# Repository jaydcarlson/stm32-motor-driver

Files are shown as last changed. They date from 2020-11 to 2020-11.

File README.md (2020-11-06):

# stm32-motor-driver
Altium PCB files and STM32CubeIDE project to implement a basic brushed DC motor controller.

## Demo Usage
The STM32 will respond to commands sent on the UART pins at a baud of 115,200. You can use [PuTTY](https://www.putty.org/) or some other serial terminal to communicate with the board using a USB-to-serial converter.

The board will announce itself on boot-up; if you don't see `STM32 Motor Driver, v1.0` printed on your console, check your TX/RX polarity, your baud, and that you are connected to the correct COM port.

The only command the interface currently supports is the "goto" command. Invoke it as `g [setpoint]`. The board will respond by announcing the setpoint and announcing when it is reached.

Examples:
```
g 1000
GO 1000...Reached

g -500
GO -500...Reached
```

## Building the Firmware
You should fork the repo on GitHub to provide you with a version-controlled environment to develop and backup your code. GitHub offers the [GitHub Desktop](https://desktop.github.com/) client, but there are many ways — including the command-line `git` tool — to manage local and remote git repositories.

You'll need STM32CubeIDE installed to build the firmware. Invoke the **File > Import**  command to open the Import dialog. 

Choose **General > Existing Projects into Workspace** and hit **Next**.

Choose the **Select root directory** radio button and hit **Browse** to select the firmware folder. STM32CubeIDE should automatically discover the project and allow you to import it by selecting it with a checkbox and clicking **Finish**.

## Pin Mapping
* PA10 and PA8 are wired as separate PWM channels (TIM1_CH3 and TIM1_CH1) for the INA and INB signals, respectively.
* PA9 is routed to the "PWM" pin — if you want to recirculate your current, keep this pin high and instead apply your PWM to the INA or INB signals. Otherwise, enable TIM1_CH2 and apply your PWM duty cycle appropriately.
* PA15 and PB3 correspond to the A and B quadrature encoder inputs, which routes them to TIM2_CH1 and TIM2_CH2 running in Encoder mode.
* PA0 (ADC1_IN0) can be used to monitor the current. The board uses a 1k CS resistor, which translates to roughly 3.696 amp at full-scale 3.3V (0.8928 V/A).
* SEL0 is routed to PA11; this can be used to determine which path inside the H-Bridge to measure current from. Consult the VNH7100 datasheet for more information.

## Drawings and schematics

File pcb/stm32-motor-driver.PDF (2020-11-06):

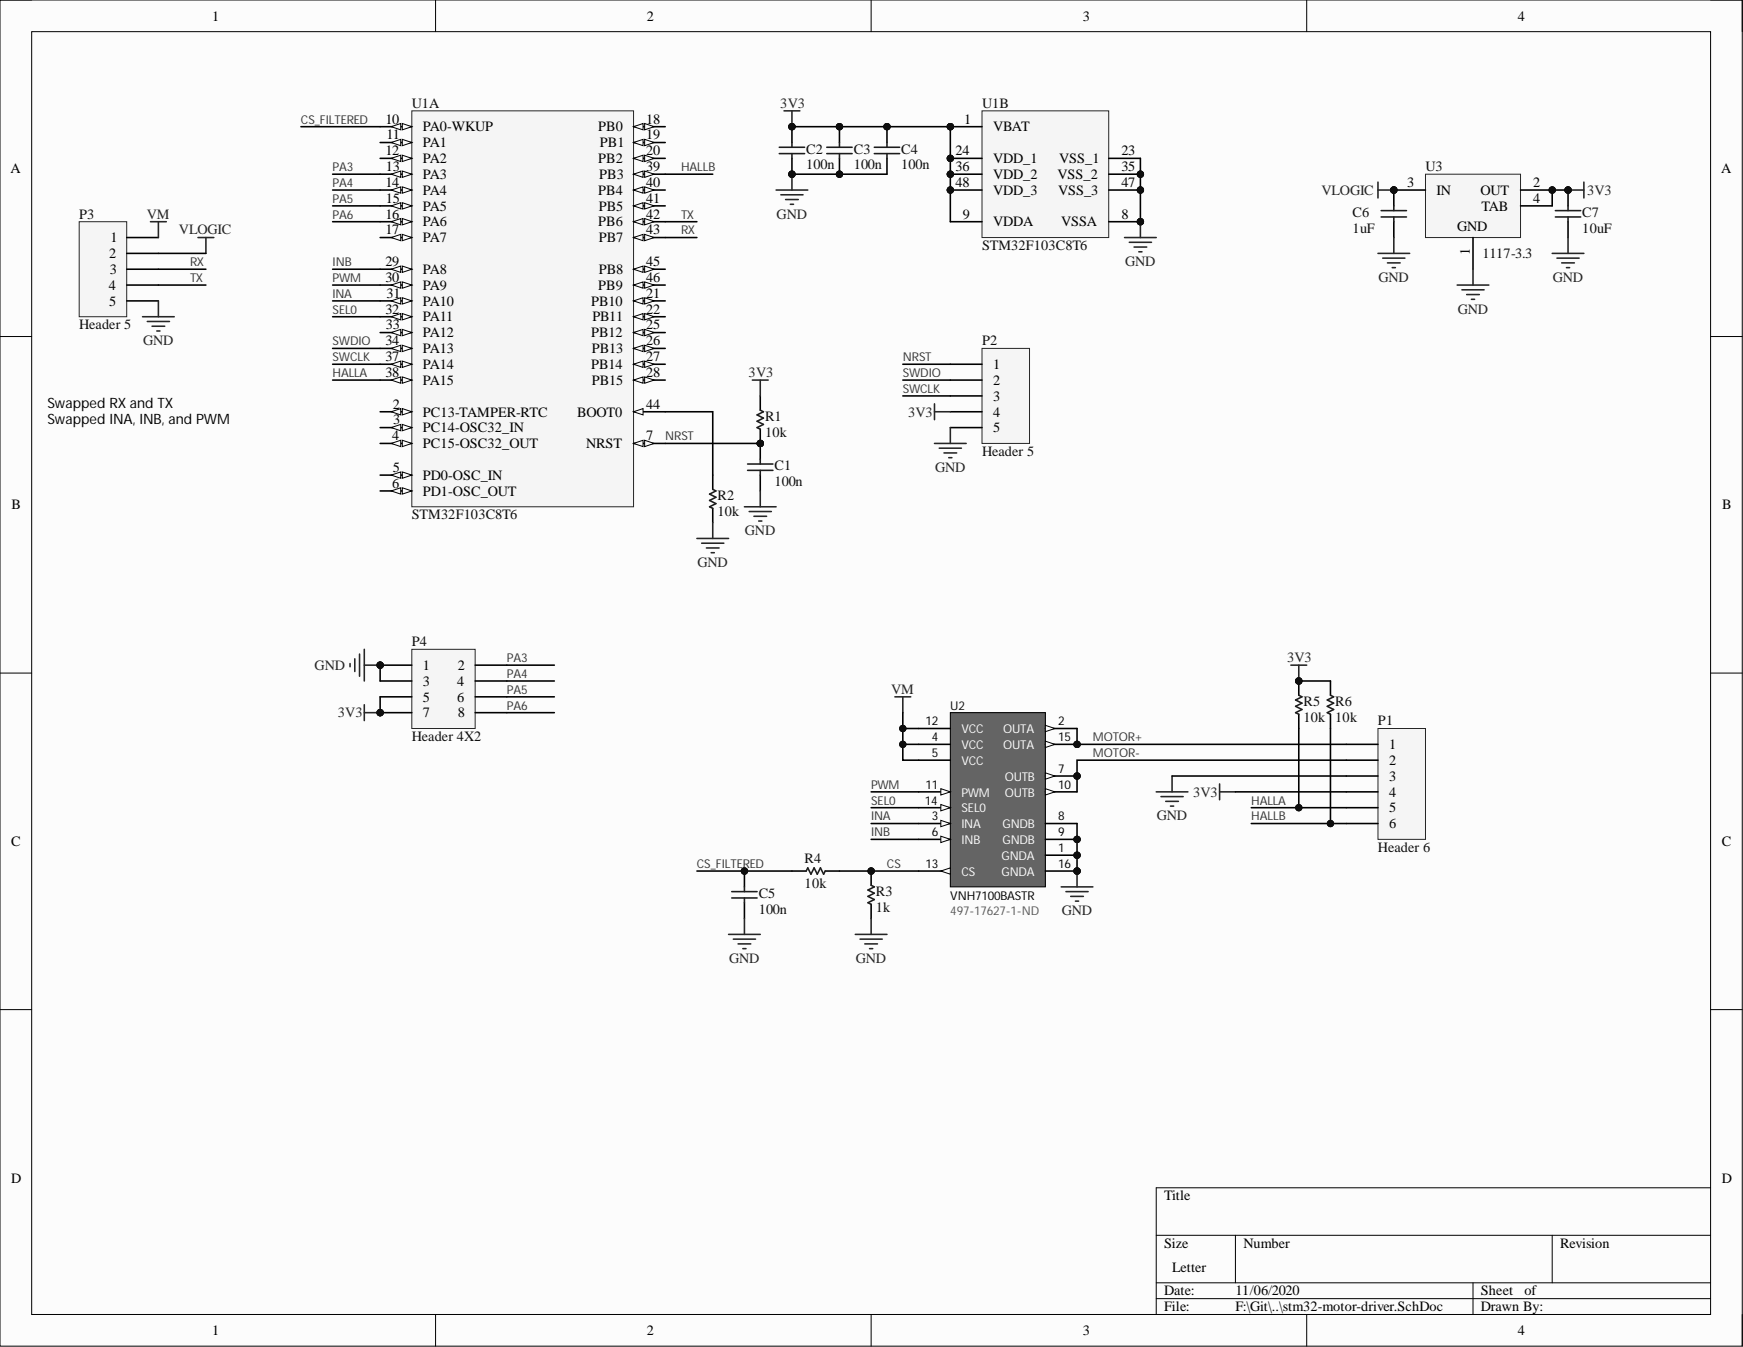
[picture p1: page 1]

Swapped RX and TX Swapped INA, INB, and PWM

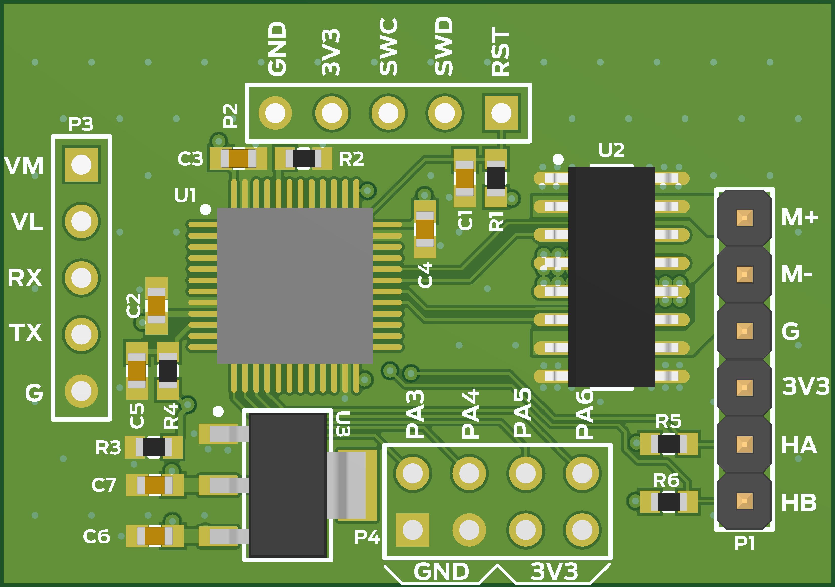
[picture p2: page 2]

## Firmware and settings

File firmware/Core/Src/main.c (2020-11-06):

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
/* Includes ------------------------------------------------------------------*/
#include "main.h"

/* USER CODE BEGIN Includes */
#include "stdlib.h"
#include "math.h"
/* USER CODE END Includes */

ADC_HandleTypeDef hadc1;

TIM_HandleTypeDef htim1;
TIM_HandleTypeDef htim2;
TIM_HandleTypeDef htim3;

UART_HandleTypeDef huart1;

void SystemClock_Config(void);
static void MX_GPIO_Init(void);
static void MX_TIM1_Init(void);
static void MX_TIM2_Init(void);
static void MX_TIM3_Init(void);
static void MX_USART1_UART_Init(void);
static void MX_ADC1_Init(void);
/* USER CODE BEGIN 0 */

int setpoint = 0;
float kp = 200.0;
int16_t currentPosition;
int error;
float integral = 0;
float ki = 1.0;
float integralLimit = 1000;
float integralFallOff = 10;
int isMoving = 0;

/**
 * This PI controller runs at a fixed rate controlled by Timer 3's ISR. See stm32f1xx_it.c's TIM3_IRQHandler() function for the call into this function.
 */
void motorTask() {
	// since we're using TIM2's hardware encoder mode, we can retrieve the current encoder value by simply reading the timer's counter
	currentPosition = (int16_t)TIM2->CNT;

	error = setpoint - currentPosition;

	if(abs(error) < 5)
	{
		// kind of a hacky toggle state machine to print "Reached" once we get *close* to the setpoint, and to do so only once.
		if(isMoving)
			HAL_UART_Transmit(&huart1, "Reached\r\n", sizeof("Reached\r\n"), 100);

		isMoving = 0;
	}


	int forward = error > 0;
	integral += error;
	integral = fmaxf(fminf(integral, integralLimit), -integralLimit); // hack so that our integral doesn't blow up

	// more hacks
	if(integral > 0)
		integral -= integralFallOff;
	if(integral < 0)
		integral += integralFallOff;

	// this is our actual PI controller update function
	float output = (kp * abs(error)) + (ki * integral);

	// clip to a 16-bit value (our PWM timer's register size)
	int dutyCycle = fminf(output, 0xFFFF);

	// depending on direction, we'll either PWM the INA or INB pin
	if(!forward)
	{
		TIM1->CCR1 = 0;			// INB = LOW
		TIM1->CCR3 = dutyCycle;	// INA = PWM
	} else {
		TIM1->CCR1 = dutyCycle; // INB = PWM
		TIM1->CCR3 = 0;			// INA = LOW
	}
}


/****
 * UART RX code
 *
 * This callback executes whenever a byte is received
 */
uint8_t line[255];
uint8_t output[255];
int column = 0;
int newSetpoint;
void HAL_UART_RxCpltCallback(UART_HandleTypeDef *huart)
{
	char rxChar = line[column-1];

	// echo the character back to the user so they can see what they typed
	HAL_UART_Transmit(&huart1, &rxChar, 1, 100);

	if(rxChar == '\r' || rxChar == '\n' || column >= 255)
	{
		// we found a carriage return or we're out of bytes. Go ahead and process the line
		switch(line[0]) // for simplicity, limit commands to a single letter
		{
		case 'g':
			// got a setpoint command
			newSetpoint = atoi(&line[2]);
			if(newSetpoint != setpoint)
			{
				setpoint = newSetpoint;
				isMoving = 1;
			}
			sprintf(output, "\r\nGO %d...", setpoint);
			HAL_UART_Transmit(&huart1, output, sizeof(output), 100);
			break;

		// add more commands here
		// case 's': // print the status
		// ...

		}

		column = 0; // reset the line buffer
	}

	HAL_UART_Receive_IT(&huart1, &line[column++], 1); // request another byte
}


/* USER CODE END 0 */

/**
  * @brief  The application entry point.
  * @retval int
  */
int main(void)
{
  /* MCU Configuration--------------------------------------------------------*/

  /* Reset of all peripherals, Initializes the Flash interface and the Systick. */
  HAL_Init();

  /* Configure the system clock */
  SystemClock_Config();

  /* Initialize all configured peripherals */
  MX_GPIO_Init();
  MX_TIM1_Init();
  MX_TIM2_Init();
  MX_TIM3_Init();
  MX_USART1_UART_Init();
  MX_ADC1_Init();
  /* USER CODE BEGIN 2 */
  HAL_TIM_PWM_Start(&htim1, TIM_CHANNEL_1);
  HAL_TIM_PWM_Start(&htim1, TIM_CHANNEL_3);
  HAL_TIM_Encoder_Start(&htim2, TIM_CHANNEL_ALL);
  HAL_TIM_Base_Start_IT(&htim3);

  HAL_UART_Receive_IT(&huart1, &line[column++], 1);
  uint8_t data[] = "STM32 Motor Driver, v1.0\r\n";
  HAL_UART_Transmit(&huart1, data, sizeof(data), 1000);
  /* USER CODE END 2 */

  /* Infinite loop */
  /* USER CODE BEGIN WHILE */
  while (1)
  {
    /* USER CODE END WHILE */

    /* USER CODE BEGIN 3 */
	  if(HAL_GPIO_ReadPin(GPIOB, GPIO_PIN_12) == 0)
	  {
		  setpoint = 0;
	  }

	  else if(HAL_GPIO_ReadPin(GPIOB, GPIO_PIN_13) == 0)
	  {
		  setpoint = 5000;
	  }

	  HAL_Delay(100); // debounce

  }
  /* USER CODE END 3 */
}

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


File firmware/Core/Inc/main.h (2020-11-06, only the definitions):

#define INB_Pin GPIO_PIN_8
#define INB_GPIO_Port GPIOA
#define PWM_Pin GPIO_PIN_9
#define PWM_GPIO_Port GPIOA
#define INA_Pin GPIO_PIN_10
#define INA_GPIO_Port GPIOA

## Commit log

2020-10-21 Add PCB
    [stm32-motor-driver.PcbDoc, stm32-motor-driver.PrjPcb, stm32-motor-driver.SchDoc]
2020-10-22 Sent off to JLC
    [stm32-motor-driver.PcbDoc, stm32-motor-driver.PrjPcb]
2020-11-06 Super simple UART demo

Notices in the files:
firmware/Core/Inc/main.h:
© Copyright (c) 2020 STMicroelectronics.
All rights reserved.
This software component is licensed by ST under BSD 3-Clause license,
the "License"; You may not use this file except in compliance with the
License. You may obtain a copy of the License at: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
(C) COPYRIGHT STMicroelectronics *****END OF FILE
